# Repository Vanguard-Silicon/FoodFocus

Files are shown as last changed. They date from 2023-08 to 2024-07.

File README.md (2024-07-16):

# FoodFocus

<h2>By <a href="https://github.com/linukaratnayake">Linuka Ratnayake</a>, <a href="https://github.com/YasiruDEX">Yasiru Basnayake</a>, <a href="https://github.com/KavinduJ2001">Kavindu Jayathissa</a>, <a href="https://github.com/KumuthuDeZoysa">Kumuthu De Zoysa</a></h2>

<div style="text-align: center;">
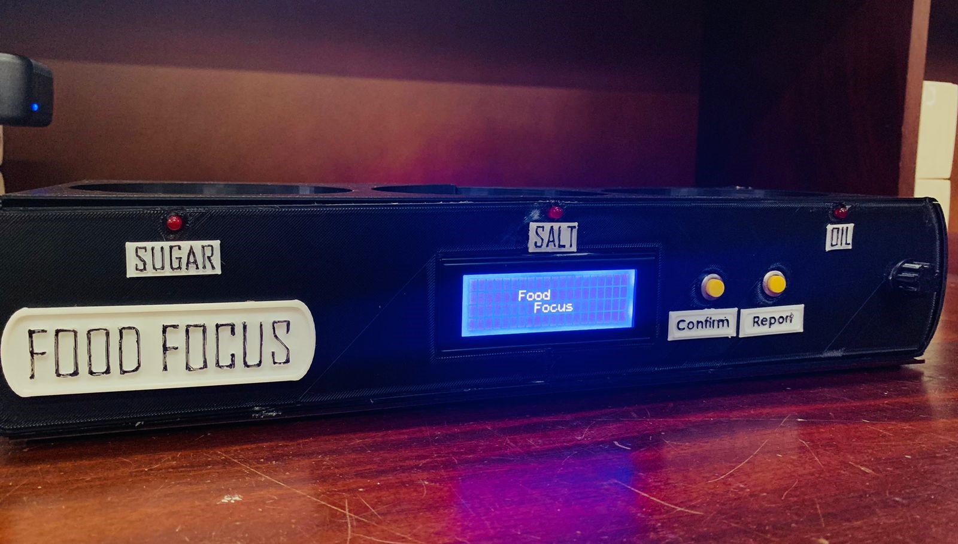
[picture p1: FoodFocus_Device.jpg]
Food Focus Device
    
</div>

FoodFocus is a device designed to track and analyze the consumption of sugar, salt, and cooking oil for individuals or groups. This is developed as a part of the EN1190: Engineering Design Project module at the Department of Electronic and Telecommunication Engineering, University of Moratuwa. This device aims to provide an effective solution for monitoring dietary intake to promote healthier eating habits.

## Motivation
A public survey revealed that while most people are aware of the health risks associated with the over-consumption of sugar, salt, and cooking oil, there is a lack of rigorous methods to measure their consumption. To address this gap, our team worked for about five months to develop FoodFocus, a comprehensive solution for tracking these dietary components.

## Features
- Weight Measurement: Utilizes load cells to measure the weights of the compartments containing sugar, salt, and cooking oil.
- Consumption Calculation: Manipulate load cell data to calculate daily consumption.
- Daily Tracking: Keeps track of daily consumption and indicates when the daily limit is reached.
- Trend Analysis: Provides detailed reports on consumption trends over time.
- Clock and Alarm: Functions as a clock and includes alarm settings to notify when food has been cooked for the required amount of time.

## PCB Design
The PCB is designed as a two-layer board using **Altium Designer**.
<div style="text-align: center;">
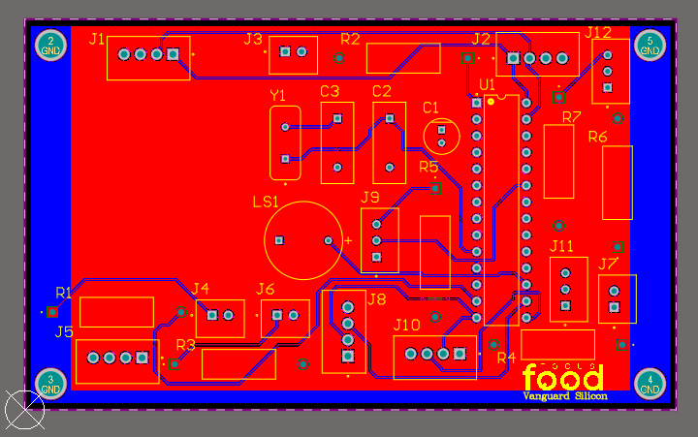
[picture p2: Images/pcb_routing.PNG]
PCB
    
</div>

<div style="text-align: center;">
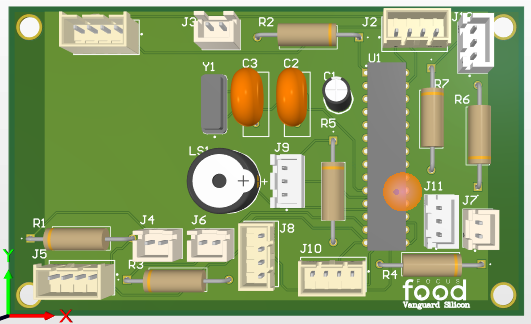
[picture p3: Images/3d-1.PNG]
3D-view
    
</div>

Schematics and PCB Design files can be found <a href="PCB Design">here</a>.

## Enclosure Design
Enclosure is designed using **SOLIDWORKS**.
<div style="text-align: center;">
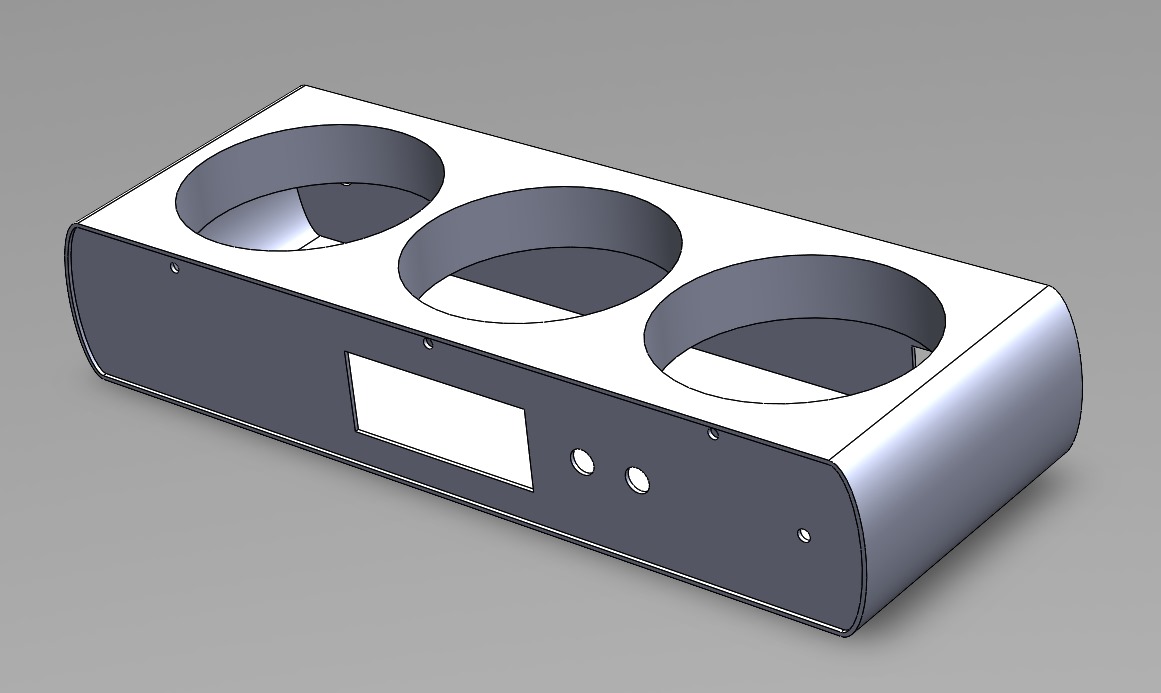
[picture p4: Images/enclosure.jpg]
Enclosure
    
</div>

Solidworks files can be found <a href="Enclosure">here</a>.

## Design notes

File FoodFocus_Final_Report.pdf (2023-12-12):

# University of Moratuwa

## Faculty of Engineering

## Department of Electronic & Telecommunication Engineering

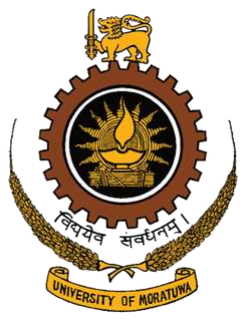
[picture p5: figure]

## EN1190 : Engineering Design Project Detailed Final Report Group Vanguard Silicon Tracker for analyzing consumption of salt, sugar and oil

## Group Members

Index No. | Name
210069F | Basnayake B.Y.N
210108C | De Zoysa A.K.N
210258J | Jayathissa R.M.K.C
210542B | Ratnayake R.M.L.H

## ABSTRACT

### Food Focus: Food Focus is a device equipped with load sensors to measure the

### weight changes in salt, sugar and oil containers. It provides a detailed report

### on the consumption of salt, sugar and oil of a household. The device is

### designed synchronized with local time and has user inputs for the number of

### family members. User can use this device as a clock as well as a timer at the

### same time while using it as a tracker. Currently, the prototype is successfully

made and consist of three primary sections: Arduino board implementation,

### circuit implementation utilizing the standalone ATmega328P and the

### designed PCB, and enclosure design. The device is also equipped with an LCD

### display for user outputs. The data collected from the load sensors is stored

### and analyzed to provide a detailed report on the usage of the ingredients. This

Food Focus will be a useful tool for households looking to monitor their salt,

### sugar and oil consumption and also to minimize waste. The enclosure of the

### device has designed using SOLIDWORKS and a special attention is providing

### for proper maintenance during the design phase. The PCB has designed using

Altium Designer in a manner to optimize the use of space.

# Contents

1. Problem Description, Motivation, and Justification | 1
2. Technical Feasibility | 2
3. Product Architecture | 2
4. UI/UX and Enclosure Design | 3
5. PCB Design | 5

6. Marketing and Sales Plan | 5
7. Bill of Quantities | 6
8. Task Allocation | 6
9. Acknowledgement | 6
10. References | 6

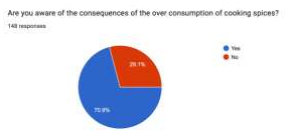
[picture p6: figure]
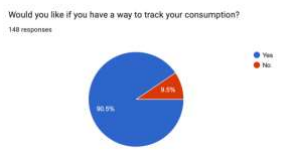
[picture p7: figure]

pg. 1

### 1.0 Problem Description

### 1.1 Raise of the Problem

This is a problem that all of our team members encountered when talking with relations, neighbors and even with our friends. Since many people have a concern on over-consumption of salt, sugar and cooking oil, we realized that this is a problem for many people. Even some people are facing health issues like diabetes, cholesterol, heart disease, high blood pressure and different kind of cancers. According to them over-consumption of salt, sugar and cooking oil is the main reason for those diseases and they were advised to control the consumption of salt, sugar and oil. But most of them did not have an idea on how to control the consumption by taking only the daily requirement.

### 1.2 Why does this problem need a

solution?

If people are in good health, they can contribute to the economy with their full potential. Also, the happiness of a family depends on the health of the family members. If a family member falls sick and require medical attention, it will be an additional cost to the family and also it will be a significant portion of the household budget. If the number of sick people increased, that country needs to invest more money on the health care and it will affect the economy as well. Therefore, by developing a device to track and analyze the consumption of the cooking spices we can help the people while contributing to the economy.

### 1.3 Who are benefited from our

product?

Since we address a problem that is faced by every individual regardless of their age and other social factors, anyone who is interested in taking care of the personal health by reducing the consumption of the salt, sugar and oil will be benefitted from our device.

### 1.4 Solution Validation

In order to validate our product idea, we conducted an online survey. It was distributed among many age groups, and here is the summery.

1. Awareness of the people of the consequences of over-consumption of cooking spices
2. Whether they want to have a way to track their consumption

3. Maximum amount they are willing to pay for a consumption tracker

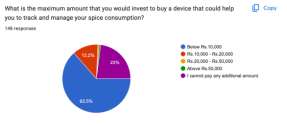
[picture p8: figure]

The conclusion taken from the observation of the survey results;

- Most of the people are aware of the consequences of the over-consumption of salt, sugar and cooking oil and they expect to have a tracker to track the consumption.
- They need the product for an affordable price.

### 2.0 Technical Feasibility

### 2.1 Technical Specification

- Dimensions:
430mmX155mmX82mm
- Platform diameter: 120mm
- Weight: 1000g (Approximately)
- Power Consumption: <0.5W
- Accuracy: Estimated error < 1
- Lifetime: 5 years, 1 year warranty
- Water resistance: No

### 2.2 Technical Feasibility

To measure the usage of salt, sugar, and cooking oil, weight sensors such as load cells, for example, the HX711, will be required for accurate weight measurements. These load cells can be connected to the ATmega328P board via its pins.

To ensure proper device functionality, all
components | must | be | integrated | and
controlled by a central controller. The ATMEGA328P microcontroller was selected for this purpose due to its optimal power consumption and availability in the market.

An LCD can be used to display information to the user. The LCD display is a popular and cost-effective option.

For calibration and resetting purposes, as well as obtaining detailed consumption reports, push buttons can be connected to the ATmega328P board.

Three LEDs are used to indicate if the user has exceeded their daily consumption limit

The device relies on the user's actions and requires good user interaction. The user should be able to easily provide input and receive feedback from the machine. To
facilitate | this, | a | LCD | display | was
incorporated into the design to display instructions and track the usage of salt, sugar, and cooking oil in a user-friendly manner.

To power the device, a 5V power supply can be provided using an AC/DC power adaptor.

### 3.0 Product Architecture

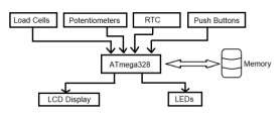
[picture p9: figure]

### 3.1 Inputs

There are two types of inputs acquired by the device.

1. User given inputs.
A. Potentiometers

Potentiometers are used to input number of family members, to navigate through the main menu, select options, set alarm time. Input is proportional to the turning of the potentiometer.

B. Push Buttons

Push buttons are used to acquire user inputs in various in various scenarios such as activating the ‘Detailed
Report’ | mode, | asking | user
confirmations on when an addition of salt, sugar or oil is detected and to
confirm | the | selection. | The
functionality of the push buttons will be described up to a satisfactory level in the product manual.
2. Internal Inputs
A. Load Cells

Three load cells has been mounted under each platform where the compartments were kept. The load cells will send real-time weight of
each | compartment | to | the
microcontroller, where those data will be processed.
B. Real Time Clock (RTC) module

An RTC module has been used to get the real time and date since they are needed for the effective analysis of the consumption over both shorter and longer period of time.

### 3.2 Output

There are two types of outputs of the device.

1. LEDs
A. An LED has been placed near each compartment to indicate if the condiment is already used more than recommended per day.
B. Power indicator
2. LCD Display

An LCD display has been used to output the calculated usage of each condiment. When the ‘Detailed Report’ mode is used, that information will also be displayed on the LCD display.

### 3.3 Storage

The collected data will be stored in a SD card module added to the ATmega328P board to store data for long term analysis, enabling the device to retrieve and analyze data later. Later on, when the user selects the ‘Detailed Report’ mode, the stored data will be
accurately | processed | and | conveniently
displayed on the LCD display, allowing for a comprehensive analysis of the gathered information.

### 4.0 UI/UX and Enclosure Design

### 4.1 UI and UX design

- The interface consists of a LCD display, confirm button and a button for the detailed report.

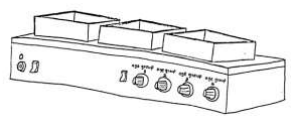
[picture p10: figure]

- The LCD display is used to display information regarding to the health report and necessary alerts.
- The multipurpose nob is for the user to navigate through the main menu and for the selections.
- At the rear of the device, the power supply is attached and a LED indicator displays the power status, with a power on/off switch.
- For the convenience of users, the compartments intended for condiments and the buttons are labeled with the corresponding names.
- ‘Sound Profile’ option is for the user to select silent mode or unmuted mode.
- ‘Detailed Report’ option has been used to provide an auditory feedback of the consumption of this month and the previous month and the trend of the usage.

### 4.2 Enclosure Design

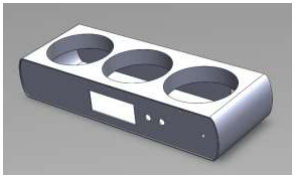
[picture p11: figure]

### 4.2.1 Initial hand drawn sketches

This initial sketches highlights the key design features and functionalities of our product, which were chosen to enhance the user experience and ensure ease of use.

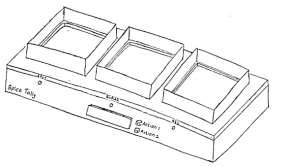
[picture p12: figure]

4.2.2 3D renders of the finalized design

These 3D renders showcases the design elements of our product, which were carefully considered and implemented to enhance the user experience and ensure ease of use. The enclosure was designed using Solid-Works.

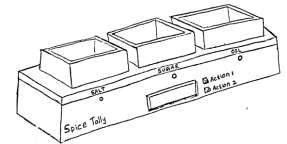
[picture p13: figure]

### 5.0 PCB Design

### 5.1 Schematic Design

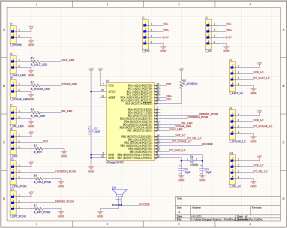
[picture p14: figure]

### 5.2 Altium Design

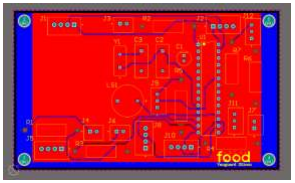
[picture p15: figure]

Routing

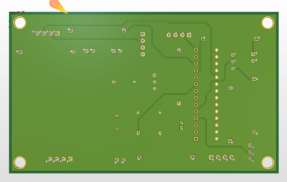
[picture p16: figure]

Bottom View

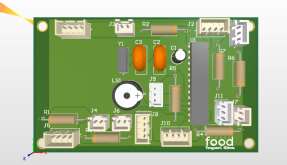
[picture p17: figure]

Top View

### 6.0 Marketing and Sales Plan

### 6.1 Marketing

- Once the prototype of the product is successfully implemented, the next stage is to build the final product design.
- It’s | important | to | maintain | clear
documentations regarding each and every step during the production process.
- Before the product is released to the
public, | it’s | mandatory | to | receive
necessary approvals from the relevant officials.
- The marketing process will be started after once the approval is received.
- The product can be marketed to the public via relevant distributers of consumer electronics.

### 6.2 Maintenance

- The device must be kept in a dry environment.
- The device can be cleaned by taking apart the removable enclosure parts.
- The device needs to be cleaned every 3 months time interval.
- In any instance of malfunctioning, repair will be done free of charge during the warranty period. (Terms and conditions apply)

### 7.0 Bill of Quantities

Components | Price(Rs)
5V power supply | 850
ATmega328P chip | 1400
Components | 10,080
PCB | 2870
Enclosure | 4500
Miscellaneous | 2900
Total | 22,600

### 8.0 Task Allocation

The responsibility of implementing the
Arduino | board | and | the | circuit
implementation | with | standalone
ATmega328P has been assigned to team member Yasiru.

The task of developing the algorithm and programming the microcontroller chip has been assigned to the team member Linuka.

Team member Kumuthu has been assigned with the responsibility of creating schematic diagrams and designing the PCB.

Team member Kavindu has been assigned with the responsibility of designing the enclosure and creating hand-drawn sketches.

### 9.0 Acknowledgement

Developing a device that analyses people’s health, within the first semester at ENTC is a challenging task that required a deep understanding of Electronics. As this was our first design project, we were facing several obstacles and had to learn numerous concepts and skills.

We extend our deepest gratitude to our
lecturer | Dr. | Ajith | Pasqual | for | their
unwavering support and guidance throughout the development process. The valuable lectures we had with Dr. Pasqual were always helpful in motivating us and clearing our doubts.

### 10.0 References

[1] Nisal Hewagamage. (2018, February 10). Sinhala Arduino Tutorial 22 - LCD Display with 2 wires using I2C module [Video]. YouTube.
https://www.youtube.com/watch?v=TLgZy LEhQiw (https://www.youtube.com/watch?v=TLgZyLEhQiw)
[2] Viral Science - The home of Creativity (2021, September 12). Arduino Digital Weight Scale HX711 Load Cell Module
[Video]. | | | YouTube.
https://www.youtube.com/watch?v=GrZzntRSAE (https://www.youtube.com/watch?v=GrZz-ntRSAE)
[3] Nisal Hewagamage. (2022, February 12).
Sinhala Arduino Tutorial 26 - RTC | DS3231
Real Time Clock Module [Video]. YouTube. https://www.youtube.com/watch?v=X-6MvZwT6ww (https://www.youtube.com/watch?v=X-6MvZwT6ww)
[4] Tech at Home. (2020, April 17). Arduino tutorial 2- LED Blink program with code
explained | How to blink an LED using
Arduino | | | [Video]. | YouTube.

https://www.youtube.com/watch?v=EJEz6t5 SpMw (https://www.youtube.com/watch?v=EJEz6t5SpMw)

[5] The Coding Train. (2017, April 11). Coding Challenge #36.1: Starfield in
Processing | [Video]. | YouTube.
https://www.youtube.com/watch?v=Sww1m ek5rHU (https://www.youtube.com/watch?v=Sww1mek5rHU)
[6] Tech Explorations. (2018, May 22). Use an LCD with Arduino in 5 Minutes
[Webpage]. | Core | Electronics.
https://coreelectronics.com.au/guides/uselcd-arduino-uno/ (https://coreelectronics.com.au/guides/use-lcd-arduino-uno/)
[7] Circuit Digest. (2021, January 7). Interfacing DS3231 RTC with Arduino and DIY Digital Clock [Webpage]. Circuit Digest.
https://circuitdigest.com/microcontrollerprojects/interfacing-ds3231-rtc-witharduino-and-diy-digital-clock (https://circuitdigest.com/microcontroller-projects/interfacing-ds3231-rtc-with-arduino-and-diy-digital-clock)
[8] Altium Designer. (n.d.). Tutorial: Complete Design Walkthrough [Webpage]. Altium.
https://www.altium.com/documentation/altium-designer/tutorial-complete-designwalkthrough (https://www.altium.com/documentation/altium-designer/tutorial-complete-design-walkthrough)
[9] SOLIDWORKS. (n.d.). SOLIDWORKS
Tutorials | [Webpage]. | SOLIDWORKS.
https://www.solidworks.com/sw/resources/s olidworks-tutorials.htm (https://www.solidworks.com/sw/resources/solidworks-tutorials.htm)
[10] AGES. (n.d.). AGES - Sugar recommendations in all phases of life
[Webpage]. | | | AGES.
https://www.ages.at/en/human/nutritionfood/nutrition-recommendations/who-sugarrecommendations (https://www.ages.at/en/human/nutrition-food/nutrition-recommendations/who-sugar-recommendations)
[11] WHO. (n.d.). Indicator Metadata
Registry | Details | [Webpage]. | WHO.
https://www.who.int/data/gho/indicatormetadata-registry/imr-details/3082 (https://www.who.int/data/gho/indicator-metadata-registry/imr-details/3082)
[12] HerZindagi English. (2020, July 24). Know which is the healthiest cooking oil and how much you can have in a day [Website].
HerZindagi | English.
https://www.herzindagi.com/recipetips/ideal-quantity-of-cooking-oil-toconsume-in-a-day-article-160982 (https://www.herzindagi.com/recipe-tips/ideal-quantity-of-cooking-oil-to-consume-in-a-day-article-160982)

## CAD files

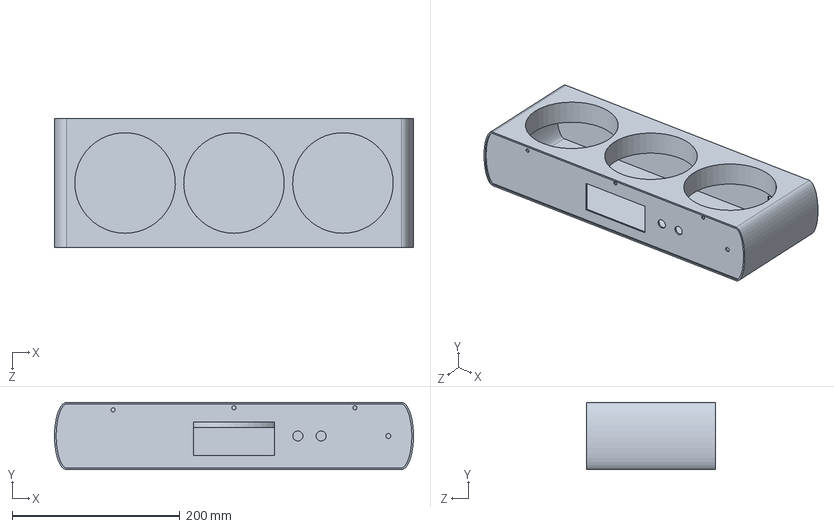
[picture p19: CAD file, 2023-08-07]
Enclosure/enclosure.SLDPRT
428.4 x 80.0 x 154.0 mm

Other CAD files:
Structural Components/Acrylic Cutting/Squares_4_pieces.dwg
Structural Components/Acrylic Cutting/LoadCell_Duino.dwg
Structural Components/Acrylic Cutting/LoadCell_Kuru.dwg
Structural Components/Acrylic Cutting/Squares_8_pieces.dwg
Structural Components/Acrylic Cutting/Platform.dwg
Enclosure/enclosure.AMF

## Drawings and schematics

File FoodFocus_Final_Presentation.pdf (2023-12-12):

## FoodFocus

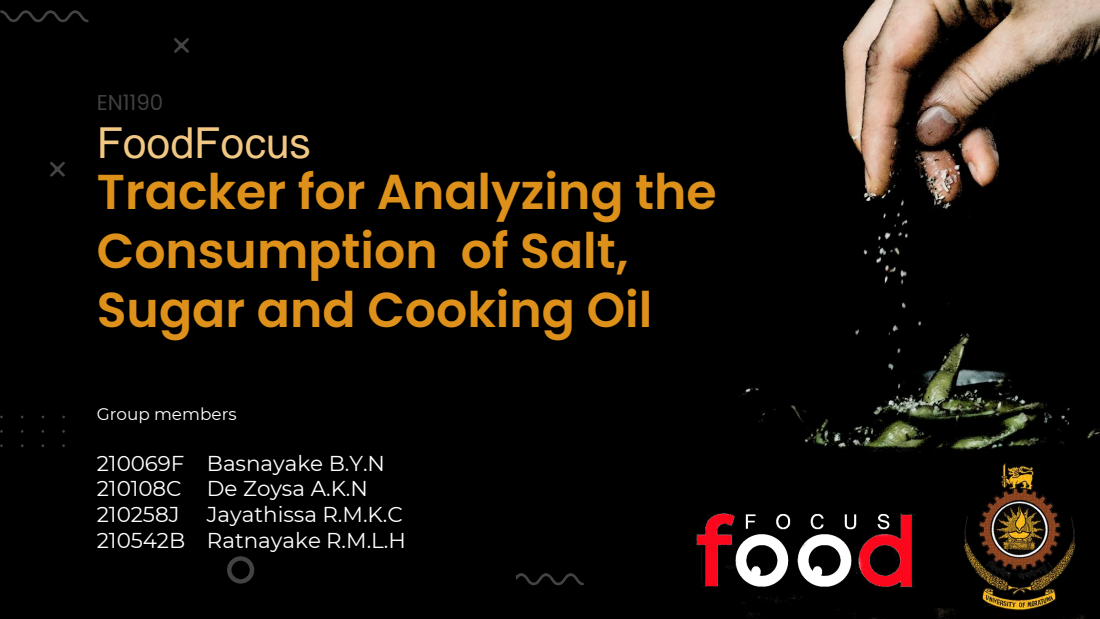
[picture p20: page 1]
Group members; 210069F Basnayake B.Y.N 210108C De Zoysa A.K.N 210258J Jayathissa R.M.K.C 210542B Ratnayake R.M.L.H

Tracker for Analyzing the
Consumption of Salt,
Sugar and Cooking Oil

# Raise of the Problem and the Solution

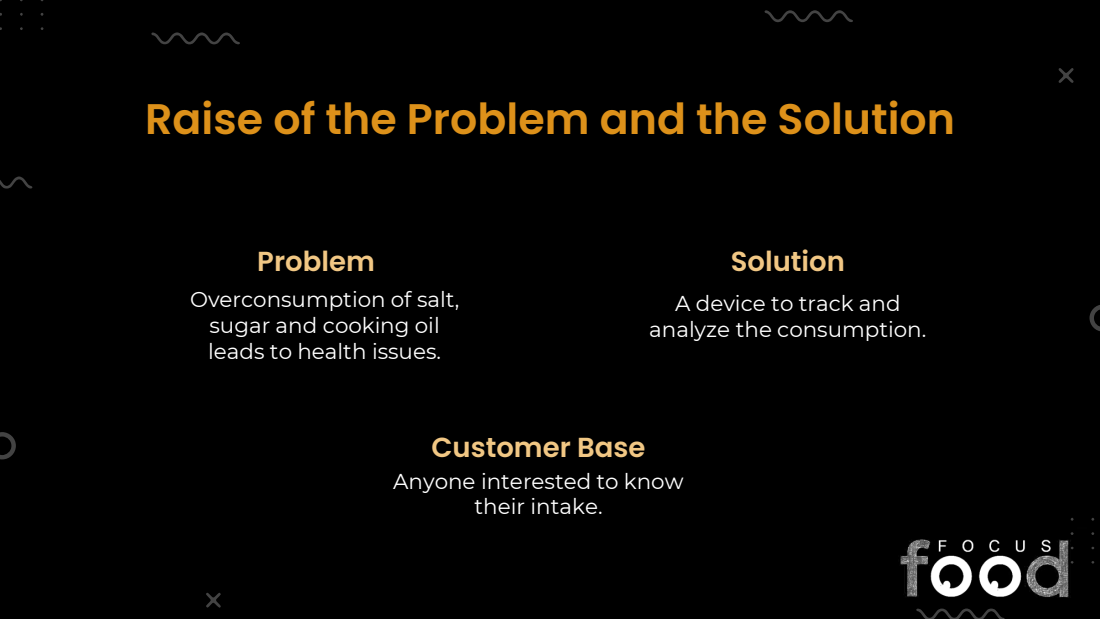
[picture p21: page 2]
their intake.

Problem
Overconsumption of salt,
sugar and cooking oil
leads to health issues.

Solution
A device to track and
analyze the consumption.

Customer Base
Anyone interested to know

# The Solution

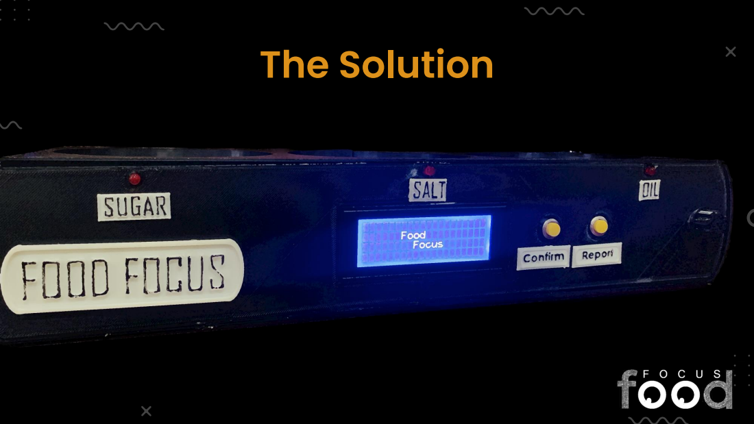
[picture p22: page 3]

# Specifications

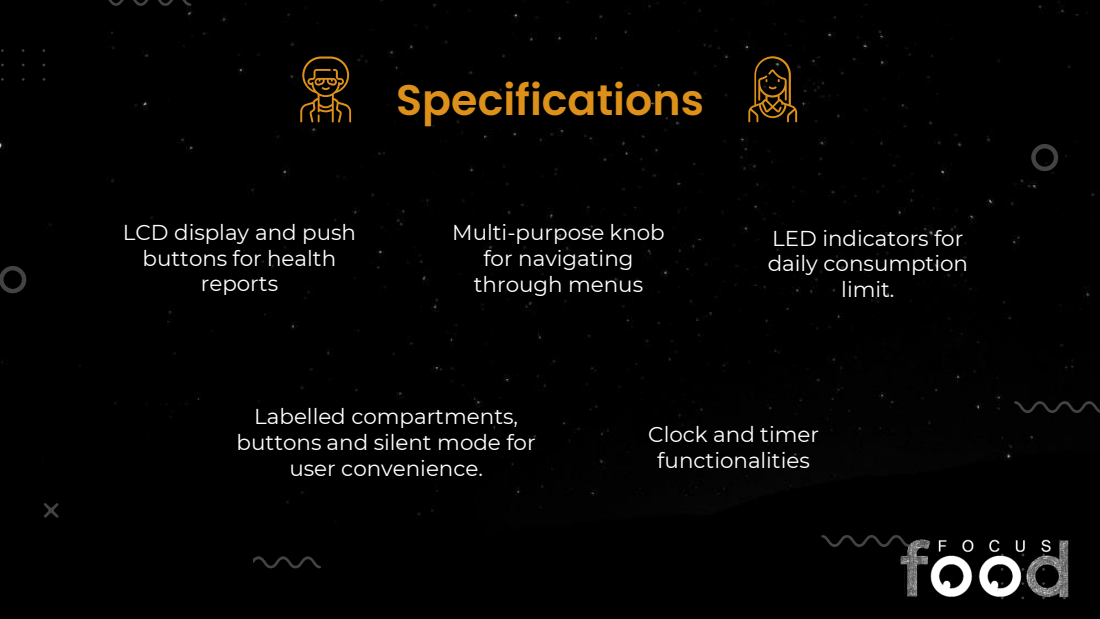
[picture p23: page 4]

LCD display and push
buttons for health
reports

Multi-purpose knob
for navigating
through menus

LED indicators for
daily consumption
limit.

Labelled compartments,
buttons and silent mode for
user convenience.

Clock and timer
functionalities

# Past, Present and Future

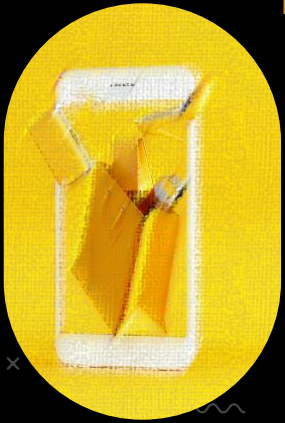
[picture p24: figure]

- Problem: People suffer from health issues because they don’t know how much salt, sugar and cooking oil they consume daily.
- Worked as a group for about five months implementing a solution.
- A ‘smart rack’-like device to keep salt, sugar and cooking oil as compartments.
- Indicates daily usage, detailed reports etc. along with clock, timer functions.
- Marketable to health-concerning individuals.

# Bill of Quantities

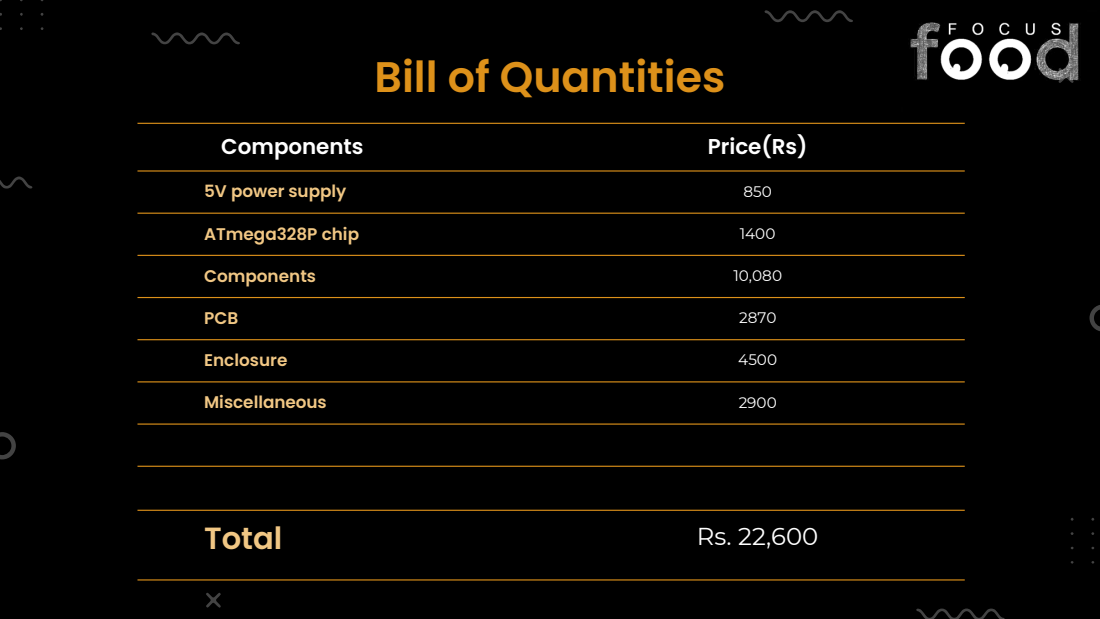
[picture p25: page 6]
Components; Price(Rs); 5V power supply; ATmega328P chip; PCB; Enclosure; Miscellaneous; Total

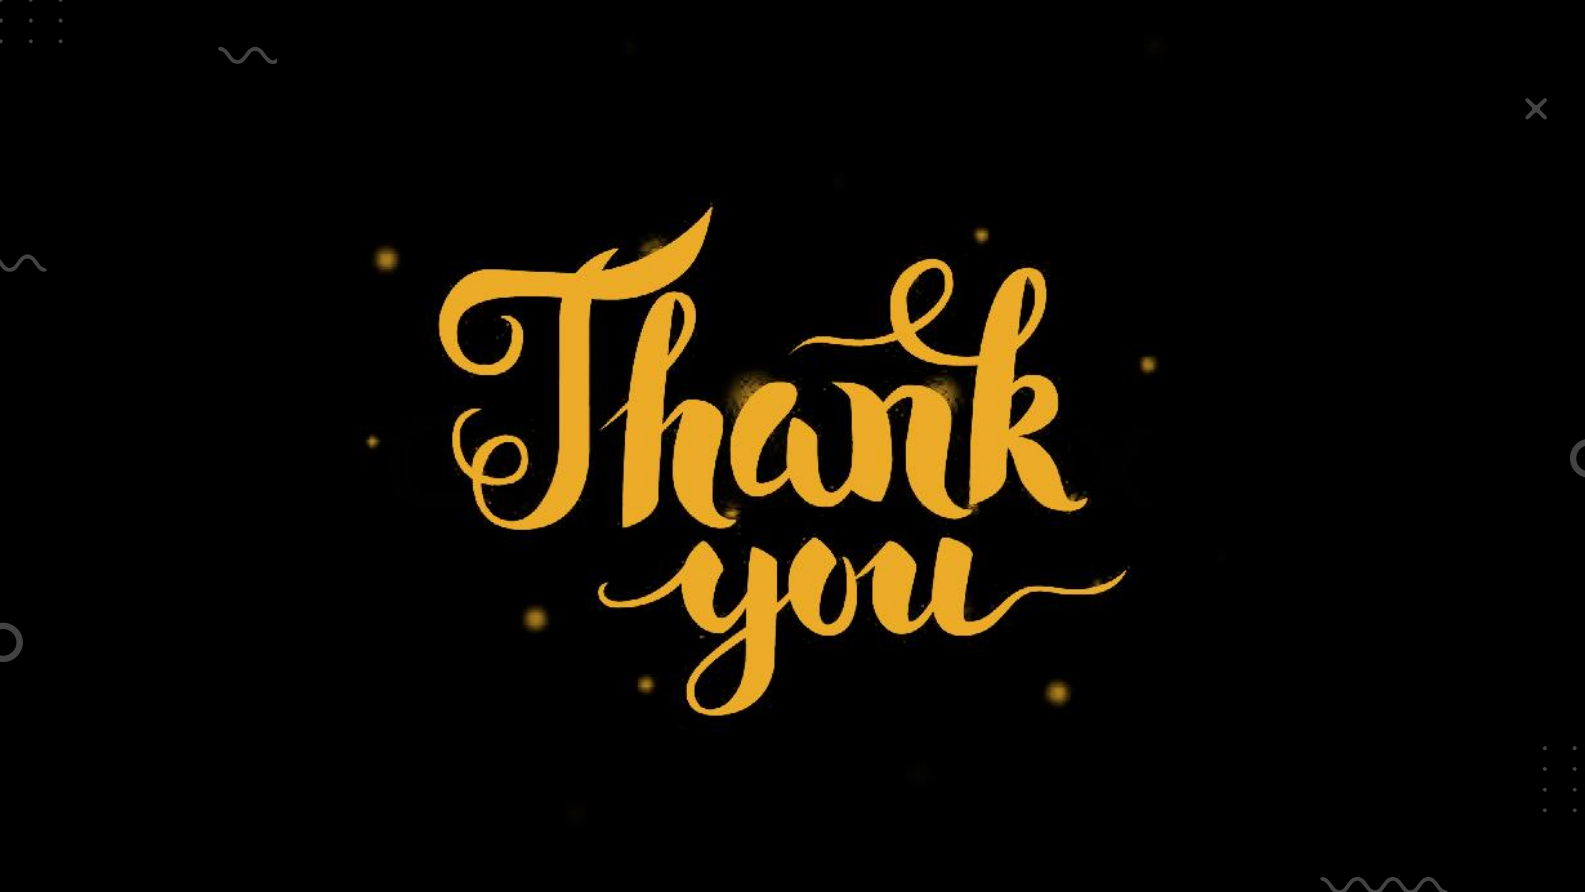
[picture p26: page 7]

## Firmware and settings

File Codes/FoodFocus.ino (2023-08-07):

#include <HX711.h>
#include <RTClib.h>
#include <EEPROM.h>
#include <Wire.h>
#include <LiquidCrystal_I2C.h>
#include "pitches.h" 11

#define SALT_LIMIT 05   // 5 grams
#define SUGAR_LIMIT 50  // 50 grams
#define OIL_LIMIT 20    // 20 grams

#define DT_LOADCELL_1 13
#define DT_LOADCELL_2 10
#define DT_LOADCELL_3 9

#define SCK_LOADCELLS 8

#define POTENTIOMETER A0

#define PUSH_BUTTON_MULTI 3
#define PUSH_BUTTON_REPORT 2

#define SALT 1
#define SUGAR 2
#define OIL 3

#define BUZZER 11

#define SALT_LED 7
#define SUGAR_LED 6
#define OIL_LED 5

#define SPICE_TOLERANCE_LOWER 1       // 1g sensitivity. Adjust necessarilly.
#define SPICE_TOLERANCE_UPPER 100     // 100g has been set as the maximum amount for one time.
#define SPICE_ADDITION_TOLERANCE 150  // Minimum 150g should be added.

#define MAX_MEMBERS 8
#define POT_VALUE 100000
#define POT_RESISTOR_VALUE 1000  // Change accordingly


bool clockState = true;
bool silentMode = false;
int soundStatus = 0;
int time;
int potPreviousVal;

HX711 scale1, scale2, scale3;
RTC_DS1307 rtc;

char *menu[] = { "<   Sound Profile  >", "<   Member Count   >", "<       Timer      >" };

int h, m, s, yr, mt, dt, dy, olds;  // hous, minutes, seconds, year, month, date of the month, day, previous second
char daysOfTheWeek[7][12] = { "Sunday", "Monday", "Tuesday", "Wednesday", "Thursday", "Friday", "Saturday" };
char *MTH[] = { "Jan", "Feb", "Mar", "Apr", "May", "Jun", "Jul", "Aug", "Sep", "Oct", "Nov", "Dec" };

float saltConsumption = 0.0, sugarConsumption = 0.0, oilConsumption = 0.0;
float saltWeight = 0.0, sugarWeight = 0.0, oilWeight = 0.0;
LiquidCrystal_I2C lcd(0x27, 20, 4);  // Default address is 0x27 (39).
bool saltBeeped = false, sugarBeeped = false, oilBeeped = false;
byte numMembers = 1;

int alarmTime = 0;
int alarmOnTime = 0;
// unsigned long systemTime;

// notes in the startup sound:
int startupMelody[] = {
  NOTE_C4, NOTE_E4, NOTE_G4, NOTE_C5
};

// note durations for the startup sound:
int startupNoteDurations[] = {
  8, 8, 8, 8
};

// Notes for the closing sound
int closingMelody[] = {
  NOTE_C5, NOTE_D5, NOTE_E5, NOTE_F5, NOTE_G5
};

// Note durations for the closing sound
int closingNoteDurations[] = {
  4, 4, 4, 4, 4
};

// Notes for the notification sound
int notificationMelody[] = {
  NOTE_A4, NOTE_E5, NOTE_A5
};

// Note durations for the notification sound
int notificationNoteDurations[] = {
  8, 8, 4
};

// Sound icon character
byte soundIcon[] = {
  B00100,
  B01101,
  B11100,
  B11101,
  B11100,
  B01101,
  B00100,
  B00000
};

// Sound icon character
byte soundOffIcon[] = {
  B10100,
  B01100,
  B11101,
  B11110,
  B11101,
  B01100,
  B10100,
  B00000
};

/////////////////////////////////////////////////////
void showClock() {


  lcd.setCursor(5, 0);
  lcd.print("Food Focus");

  // read all time and date and display
  DateTime now = rtc.now();
  h = now.hour();
  m = now.minute();
  s = now.second();
  yr = now.year();
  mt = now.month();
  dt = now.day();
  dy = now.dayOfTheWeek();
  olds = s;

  // fill the display with all the data
  printbig((h % 10), 3);
  printbig((h / 10), 0);
  printbig((m % 10), 10);
  printbig((m / 10), 7);
  printbig((s % 10), 17);
  printbig((s / 10), 14);

  lcd.setCursor(3, 3);
  lcd.print(MTH[mt - 1]);
  lcd.setCursor(7, 3);
  lcd.print(dt / 10);
  lcd.print(dt % 10);
  lcd.setCursor(10, 3);
  lcd.print(daysOfTheWeek[dy]);

  s = now.second();          // read seconds
  if (olds != s) {           // if seconds changed
    printbig((s % 10), 17);  // display seconds
    printbig((s / 10), 14);
    olds = s;
    if (s == 0) {              // minutes change
      m = now.minute();        // read minutes
      printbig((m % 10), 10);  // display minutes
      printbig((m / 10), 7);
      if (m == 0) {             // hours change
        h = now.hour();         // read hours
        printbig((h % 10), 3);  // dislay hours
        printbig((h / 10), 0);
        if (h == 0) {      // day change
          dt = now.day();  // read day
          dy = now.dayOfTheWeek();
          mt = now.month();  // read month
          yr = now.year();   // read year
          lcd.setCursor(3, 3);
          lcd.print(MTH[mt]);
          lcd.setCursor(7, 3);
          lcd.print(dt / 10);
          lcd.print(dt % 10);
          lcd.setCursor(10, 3);
          lcd.print(daysOfTheWeek[dy]);
        }
      }
    }
  }
}

int potRead() {
  return 1023 - analogRead(A0);
}

void printbig(int i, int x) {
  //  prints each segment of the big numbers

  if (i == 0) {
    lcd.setCursor(x, 1);
    lcd.write(8);
    lcd.write(1);
    lcd.write(2);
    lcd.setCursor(x, 2);
    lcd.write(3);
    lcd.write(4);
    lcd.write(5);
  } else if (i == 1) {
    lcd.setCursor(x, 1);
    lcd.write(8);
    lcd.write(255);
    lcd.print(" ");
    lcd.setCursor(x, 2);
    lcd.print(" ");
    lcd.write(255);
    lcd.print(" ");
  }

  else if (i == 2) {
    lcd.setCursor(x, 1);
    lcd.write(1);
    lcd.write(6);
    lcd.write(2);
    lcd.setCursor(x, 2);
    lcd.write(3);
    lcd.write(7);
    lcd.write(4);
  }

  else if (i == 3) {
    lcd.setCursor(x, 1);
    lcd.write(1);
    lcd.write(6);
    lcd.write(2);
    lcd.setCursor(x, 2);
    lcd.write(4);
    lcd.write(7);
    lcd.write(5);
  }

  else if (i == 4) {
    lcd.setCursor(x, 1);
    lcd.write(3);
    lcd.write(4);
    lcd.write(2);
    lcd.setCursor(x, 2);
    lcd.print("  ");
    lcd.write(5);
  }

  else if (i == 5) {
    lcd.setCursor(x, 1);
    lcd.write(255);
    lcd.write(6);
    lcd.write(1);
    lcd.setCursor(x, 2);
    lcd.write(7);
    lcd.write(7);
    lcd.write(5);
  }

  else if (i == 6) {
    lcd.setCursor(x, 1);
    lcd.write(8);
    lcd.write(6);
    lcd.print(" ");
    lcd.setCursor(x, 2);
    lcd.write(3);
    lcd.write(7);
    lcd.write(5);
  }

  else if (i == 7) {
    lcd.setCursor(x, 1);
    lcd.write(1);
    lcd.write(1);
    lcd.write(5);
    lcd.setCursor(x, 2);
    lcd.print(" ");
    lcd.write(8);
    lcd.print(" ");
  }

  else if (i == 8) {
    lcd.setCursor(x, 1);
    lcd.write(8);
    lcd.write(6);
    lcd.write(2);
    lcd.setCursor(x, 2);
    lcd.write(3);
    lcd.write(7);
    lcd.write(5);
  }

  else if (i == 9) {
    lcd.setCursor(x, 1);
    lcd.write(8);
    lcd.write(6);
    lcd.write(2);
    lcd.setCursor(x, 2);
    lcd.print(" ");
    lcd.write(4);
    lcd.write(5);
  }
}

void playMelody(int melody[], int noteDurations[], int length) {
  if (silentMode == true) { return true; }
  for (int thisNote = 0; thisNote < length; thisNote++) {
    int noteDuration = 1000 / noteDurations[thisNote];
    tone(BUZZER, melody[thisNote], noteDuration);
    int pauseBetweenNotes = noteDuration * 1.30;
    delay(pauseBetweenNotes);
    noTone(BUZZER);
  }
}

byte getMembers() {
  return numMembers;
  const float lowerValue = POT_RESISTOR_VALUE / (POT_RESISTOR_VALUE + POT_VALUE) * 5;
  return (int)(((1023 - analogRead(POTENTIOMETER)) / 1023.0 * 4.9) / (5 - lowerValue) * (MAX_MEMBERS) + 1);
  //return (int) ((analogRead(POTENTIOMETER)));
}

// This plays an animation when booting up the device.
void bootup() {
  //return true;
  const int delayTime = 500;
  lcd.clear();
  lcd.setCursor(6, 1);
  lcd.print(" o d");
  delay(delayTime);
  lcd.setCursor(8, 2);
  lcd.print(" o u");
  delay(delayTime);
  lcd.setCursor(6, 1);
  lcd.print("Fo d");
  delay(delayTime);
  lcd.setCursor(8, 2);
  lcd.print("Fo us");
  delay(delayTime);
  lcd.setCursor(6, 1);
  lcd.print("Food");
  delay(delayTime);
  lcd.setCursor(8, 2);
  lcd.print("Focus");
  delay(delayTime * 5);

  lcd.clear();
  lcd.setCursor(2, 2);
  lcd.print("Initializing.");
  delay(delayTime * 3);

  lcd.setCursor(2, 2);
  lcd.print("Initializing..");
  delay(delayTime * 3);

  lcd.setCursor(2, 2);
  lcd.print("Initializing...");
  playMelody(startupMelody, startupNoteDurations, 4);
  lcd.clear();
}

float getWeight(int cellNumber) {
  if (cellNumber == 1)
    return scale1.get_units();
  else if (cellNumber == 2)
    return scale2.get_units();
  else if (cellNumber == 3)
    return scale3.get_units();
}

void calibrateLoadCell(HX711 *scale, float value) {
  scale->set_scale(value);  // This will give answers in grams.
}

void justConsumed(int spice, float usage) {
  // A float is usually 4 bytes.
  if (spice == SALT) {
    saltConsumption += usage;
    saltWeight -= usage;
    EEPROM.put(0, saltConsumption);  // EEPROM address 0 (0 1 2 3)
  }
  if (spice == SUGAR) {
    sugarConsumption += usage;
    sugarWeight -= usage;
    EEPROM.put(sizeof(float), sugarConsumption);  // EEPROM address 4 (4 5 6 7)
  }
  if (spice == OIL) {
    oilConsumption += usage;
    oilWeight -= usage;
    EEPROM.put(2 * sizeof(float), oilConsumption);  // EEPROM address 8 (8 9 10 11)
  }

  // First 12 bytes of the EEPROM is used to store the current usage of the day.
  // Using EEPROM reduces the lost of data in case of a power failure.
}

void justAdded(int spice, float addition) {
  if (spice == SALT) {
    saltWeight += addition;
  }
  if (spice == SUGAR) {
    sugarWeight += addition;
  }
  if (spice == OIL) {
    oilWeight += addition;
  }
}

bool confirmAddition(int spice) {
  //digitalWrite(BUZZER, HIGH);
  playMelody(notificationMelody, notificationNoteDurations, 3);

  unsigned long time = millis();

  lcd.clear();
  String spiceName = "";
  if (spice == SALT) spiceName = "Salt";
  else if (spice == SUGAR) spiceName = "Sugar";
  else if (spice == OIL) spiceName = "Oil";

  lcd.setCursor(0, 0);
  lcd.print("Did you add " + spiceName + "?");
  lcd.setCursor(0, 2);
  lcd.print("Press \"Confirm\"");
  lcd.setCursor(0, 3);
  lcd.print("button to confirm.");

  if (spice == SALT) {
    digitalWrite(SALT_LED, HIGH);
  } else if (spice == SUGAR) {
    digitalWrite(SUGAR_LED, HIGH);
  } else if (spice == OIL) {
    digitalWrite(OIL_LED, HIGH);
  }

  // The program will wait for 5 seconds for the user confirmation
  while (millis() - time <= 5000) {
    //lcd.setCursor(0, 1);
    //lcd.print("first");
    if (millis() - time >= 1000) {
      digitalWrite(BUZZER, LOW);
    }
    if (digitalRead(PUSH_BUTTON_MULTI) == HIGH) {
      // Confirmed.
      if (spice == SALT) {
        digitalWrite(SALT_LED, LOW);
        digitalWrite(BUZZER, LOW);
      } else if (spice == SUGAR) {
        digitalWrite(SUGAR_LED, LOW);
        digitalWrite(BUZZER, LOW);
      } else if (spice == OIL) {
        digitalWrite(OIL_LED, LOW);
        digitalWrite(BUZZER, LOW);
      }
      lcd.clear();
      return true;
    }
  }
  lcd.clear();
  return false;
}

typedef struct {
  byte numOfMembers;
  byte month;
  byte day;
  float saltConsumption;
  float sugarConsumption;
  float oilConsumption;
} consumptionData;

void storeConsumption() {
  DateTime dateTime = rtc.now();
  float consumptionSalt, consumptionSugar, consumptionOil;
  EEPROM.get(0, consumptionSalt);
  EEPROM.get(sizeof(float), consumptionSugar);
  EEPROM.get(2 * sizeof(float), consumptionOil);
  consumptionData consumption = { (byte)getMembers(), (byte)dateTime.month(), (byte)dateTime.day(),
                                  (float)(consumptionSalt), (float)(consumptionSugar), (float)(consumptionOil) };

  int storeIndex = 20 + (dateTime.day() * sizeof(consumptionData));  // The struct has a size of 8 bytes
  EEPROM.put(storeIndex, consumption);
}

typedef struct mA {
  float saltAverage;
  float sugarAverage;
  float oilAverage;
} monthlyAverage;

// Seems like the direct use of the typedef name in function return type is not working.
struct mA calculateTheAverage(int days) {
  float pastMonth[3] = {};
  consumptionData temp;
  for (int i = 1; i <= days; i++) {
    EEPROM.get(20 + i * sizeof(consumptionData), temp);
    pastMonth[SALT - 1] += (float)temp.saltConsumption / temp.numOfMembers;
    pastMonth[SUGAR - 1] += (float)temp.sugarConsumption / temp.numOfMembers;
    pastMonth[OIL - 1] += (float)temp.oilConsumption / temp.numOfMembers;
  }
  // Dividing by 30 is not exactly correct, as not every month has 30 days, specially the current month.
  // But, it has been used for simplicity, otherwise more data such as the current day in the month need to be taken into account.
  static monthlyAverage averages = { pastMonth[SALT - 1] / 30, pastMonth[SUGAR - 1] / 30, pastMonth[OIL - 1] / 30 };

  return averages;
}
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
void loop() {
  if (silentMode){lcd.setCursor(19, 0);lcd.print("x");}
  

  if ((int(millis() / 1000) % 20) < 5) {
    if (clockState) {
      lcd.clear();
      clockState = false;
    }
    //lcd.clear();
    showClock();
  }

  if (abs(potPreviousVal - potRead()) > 200) {
    lcd.clear();
    int time = int(millis() / 1000);
    potPreviousVal = potRead();

    while (int(millis() / 1000) - time < 7) {
      lcd.setCursor(4, 0);
      lcd.print("--MAIN MENU--");

      if (potRead() < 341) {

        if (soundStatus != 1){soundStatus = 1; if(!silentMode){tone(BUZZER, NOTE_A1, 16);} delay(20.8);}

        lcd.setCursor(0, 2);
        lcd.print(menu[0]);
        if (digitalRead(3) == 1) {
          delay(200);
          int time = int(millis() / 1000);
          potPreviousVal = potRead();

          while (int(millis() / 1000) - time < 3) {

            if (abs(potPreviousVal - potRead()) > 100) {
              time = int(millis() / 1000);
              potPreviousVal = potRead();
            }

            if (potPreviousVal < 500) {
              if (soundStatus != 2){soundStatus = 2; if(!silentMode){tone(BUZZER, NOTE_A1, 16);} delay(20.8);}

              lcd.setCursor(0, 2);
              lcd.print("Silent Mode: < OFF >");
              if (digitalRead(3) == 1) {
                silentMode = false;
                time = int(millis() / 1000) - 10;
                delay(200);
                potPreviousVal = potRead();
              }
            } else {
              if (soundStatus != 3){soundStatus = 3; if(!silentMode){tone(BUZZER, NOTE_A1, 16);} delay(20.8);}

              lcd.setCursor(0, 2);
              lcd.print("Silent Mode: < ON  >");
              if (digitalRead(3) == 1) {
                silentMode = true;
                time = int(millis() / 1000) - 10;
                delay(200);
                potPreviousVal = potRead();
              }
            }
          }
        }

      } else if (potRead() < 682) {
        if (soundStatus != 4){soundStatus = 4; if(!silentMode){tone(BUZZER, NOTE_A1, 16);} delay(20.8);}

        lcd.setCursor(0, 2);
        lcd.print(menu[1]);
        if (digitalRead(3) == 1) {
          delay(200);
          int time = int(millis() / 1000);
          int potPreviousVal = potRead();

          while (int(millis() / 1000) - time < 3) {

            if (abs(potPreviousVal - potRead()) > 100) {
              if(!silentMode){tone(BUZZER, NOTE_A1, 16);} delay(20.8);
              time = int(millis() / 1000);
              potPreviousVal = potRead();
            }

            lcd.setCursor(0, 2);
            lcd.print("Member Count:  < " + String(int(potPreviousVal / 120) + 1) + " >");
            if (digitalRead(3) == 1) {
              if (soundStatus != 5){soundStatus = 5; playMelody(notificationMelody, notificationNoteDurations, 3); delay(20.8);}

              numMembers = int(potPreviousVal / 120) + 1;
              time = int(millis() / 1000) - 10;
              delay(200);
              lcd.clear();
              lcd.setCursor(0, 2);
              lcd.print("   Member Count: " + String(int(potPreviousVal / 120) + 1));
              delay(1000);
              potPreviousVal = potRead();
            }
          }
        }

      } else {
        if (soundStatus != 6){soundStatus = 6; if(!silentMode){tone(BUZZER, NOTE_A1, 16);} delay(20.8);}

        delay(200);
        lcd.setCursor(0, 2);
        lcd.print(menu[2]);
        if (digitalRead(3) == 1) {
          delay(200);
          int time = int(millis() / 1000);
          int potPreviousVal = potRead();

          while (int(millis() / 1000) - time < 3) {

            if (abs(potPreviousVal - potRead()) > 50) {
              if(!silentMode){tone(BUZZER, NOTE_A1, 16);} delay(20.8);
              time = int(millis() / 1000);
              potPreviousVal = potRead();
            }

            lcd.setCursor(0, 2);
            lcd.print("Timer:  < " + String(int(potPreviousVal / 6) + 1) + "  ");
            lcd.setCursor(14, 2);
            lcd.print(" min >");
            if (digitalRead(3) == 1) {
              if (soundStatus != 7){soundStatus = 7; playMelody(notificationMelody, notificationNoteDurations, 3); delay(20.8);}
              alarmTime = (int(potPreviousVal / 6) + 1) * 60;
              alarmOnTime = int(millis() / 1000);
              time = int(millis() / 1000) - 10;
              delay(200);
              lcd.clear();
              lcd.setCursor(0, 2);
              lcd.print("  Timer in " + String(int(potPreviousVal / 6 + 1)) + " mins");
              delay(1000);
              potPreviousVal = potRead();
            }
          }
        }
      }
    }
    lcd.clear();

    if (alarmTime != 0) {
      //lcd.setCursor(0, 2);
      //lcd.print("Alarm on");
      //delay(400);
      if ((int(millis() / 1000) - alarmOnTime) > alarmTime) {
        //lcd.print("Alarm ON");
        //delay(400);
        alarmTime = 0;
        while (true) {
          digitalWrite(BUZZER, HIGH);
          lcd.print("Time's up");
          delay(400);
          if (digitalRead(3) == 1) {
            break;
          }
        }
        digitalWrite(BUZZER, LOW);
      }
    }

    potPreviousVal = potRead();
  }

  DateTime now = rtc.now();
  int currentDate;
  int currentMonth;
  EEPROM.get(12, currentDate);
  EEPROM.get(14, currentMonth);

  if (now.day() != currentDate) {  // New date has started.
    // Store the consumption so far
    storeConsumption();

    // Reset the daily consumption to zero.
    saltConsumption = 0.0;
    sugarConsumption = 0.0;
    oilConsumption = 0.0;
    // Turn of the indicator LEDs
    digitalWrite(SALT_LED, LOW);
    digitalWrite(SUGAR_LED, LOW);
    digitalWrite(OIL_LED, LOW);

    saltBeeped = false;
    sugarBeeped = false;
    oilBeeped = false;

    // Set the new day to EEPROM
    EEPROM.put(12, (int)rtc.now().day());
  }

  if (now.month() != currentMonth) {
    monthlyAverage averages = calculateTheAverage(28);  // This can be 28, 29 (Feb) or 30, 31. The value 28 is used for ease.
    int monthCount;
    EEPROM.get(16, monthCount);
    EEPROM.put(500 + monthCount * sizeof(monthlyAverage), averages);
    EEPROM.put(16, monthCount + 1);
  }

  float instantSaltWeight = getWeight(SALT);
  float instantSugarWeight = getWeight(SUGAR);
  float instantOilWeight = getWeight(OIL);

  float saltUsage = saltWeight - instantSaltWeight;
  if (saltUsage >= SPICE_TOLERANCE_LOWER && saltUsage <= SPICE_TOLERANCE_UPPER){  // Salt is consumed.
    delay(500);
    instantSaltWeight = getWeight(SALT);
    saltUsage = saltWeight - instantSaltWeight;
    if (saltUsage >= SPICE_TOLERANCE_LOWER && saltUsage <= SPICE_TOLERANCE_UPPER)
      justConsumed(SALT, saltUsage);
  }

  float sugarUsage = sugarWeight - instantSugarWeight;
  if (sugarUsage >= SPICE_TOLERANCE_LOWER && sugarUsage <= SPICE_TOLERANCE_UPPER){  // Sugar is consumed.
    delay(500);
    instantSugarWeight = getWeight(SUGAR);
    sugarUsage = sugarWeight - instantSugarWeight;
    if (sugarUsage >= SPICE_TOLERANCE_LOWER && sugarUsage <= SPICE_TOLERANCE_UPPER)
      justConsumed(SUGAR, sugarUsage);
  }

  float oilUsage = oilWeight - instantOilWeight;
  if (oilUsage >= SPICE_TOLERANCE_LOWER && oilUsage <= SPICE_TOLERANCE_UPPER){  // Oil is consumed.
    delay(500);
    instantOilWeight = getWeight(OIL);
    oilUsage = oilWeight - instantOilWeight;
    if (oilUsage >= SPICE_TOLERANCE_LOWER && oilUsage <= SPICE_TOLERANCE_UPPER)
      justConsumed(OIL, oilUsage);
  }

  // Serial.print(String(saltWeight) + "\t" + String(saltConsumption) + "\t\t");
  // Serial.print(String(sugarWeight) + "\t" + String(sugarConsumption) + "\t\t");
  // Serial.println(String(oilWeight) + "\t" + String(oilConsumption));
  if ((int(millis() / 1000) % 20) > 5) {
    if (clockState == false) {
      lcd.clear();
      clockState = true;
    }
    //lcd.clear();
    lcd.setCursor(1, 0);
    lcd.print("Today's Usage (g)");
    lcd.setCursor(0, 1);
    lcd.print("Sugar |");
    lcd.setCursor(0, 2);
    lcd.print("Salt  |");
    lcd.setCursor(0, 3);
    lcd.print("Oil   |");

    lcd.setCursor(15, 1);
    lcd.print("/");
    lcd.setCursor(15, 2);
    lcd.print("/");
    lcd.setCursor(15, 3);
    lcd.print("/");

    lcd.setCursor(17, 1);
    lcd.print(SUGAR_LIMIT * getMembers());
    lcd.setCursor(17, 2);
    lcd.print(SALT_LIMIT * getMembers());
    lcd.setCursor(17, 3);
    lcd.print(OIL_LIMIT * getMembers());

    lcd.setCursor(8, 1);
    lcd.print(sugarConsumption, 2);
    lcd.setCursor(8, 2);
    lcd.print(saltConsumption, 2);
    lcd.setCursor(8, 3);
    lcd.print(oilConsumption, 2);
  }
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
